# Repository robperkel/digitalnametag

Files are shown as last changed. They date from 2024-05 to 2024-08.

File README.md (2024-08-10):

# E-Paper Digital Nametag

This projects creates a simple re-programmable E-Paper Nametag with the AVR64DU32 microcontroller (MCU). The MCU enumerates as a standard COM serial port when plugged into a computer. 

## Licensing

### Software 
- Code that is automatically generated by MPLAB&reg; Code Configurator (MCC) or pulled from a code example is licensed by Microchip (full agreement is in the header files).
    - The short version is that it is free to use/modify, so long as it uses a Microchip MCU.
- Code that I wrote (firmware and image loading scripts) is licensed under GNU AGPL v3
    - https://choosealicense.com/licenses/agpl-3.0/ 

### Hardware 

- Hardware Design (Schematic and PCB files) are licensed under CERN OHL v2
    - https://choosealicense.com/licenses/cern-ohl-s-2.0/
- 3D models for parts in the PCB are not included due to licensing restrictions. 

## Python Libraries Required (Not Included)

- [Python Image Library (Pillow)](https://pypi.org/project/pillow/)
    - This library opens the image and reads the pixel values.
- [pySerial](https://pypi.org/project/pyserial/)
    - This library allows the script to send data over a COM port.

## Image Configuration  

- Size must be 212 x 104 pixels 
- Colors must only be Red/Black/White
    - The easiest way to achieve this is to use Indexed Color Mode in your image editor
        - Red = 0xFF0000 [255, 0, 0]
        - Black = 0x000000 [0, 0, 0]
        - White = 0xFFFFFF [255, 255, 255]

A test image is provided in the Images folder.

## Programming Connector

This board is designed to use a 6 position Tag-Connect header (such as a [TC2030-ICESPI](https://www.tag-connect.com/product/tc2030-icespi-legged-cable-for-use-with-atmel-ice)) for programming. 

It should be possible to carefully solder wires to the same programming pads to program without this connector, although this may prevent the use of a Tag-Connect header in the future due to the uneven surface created.

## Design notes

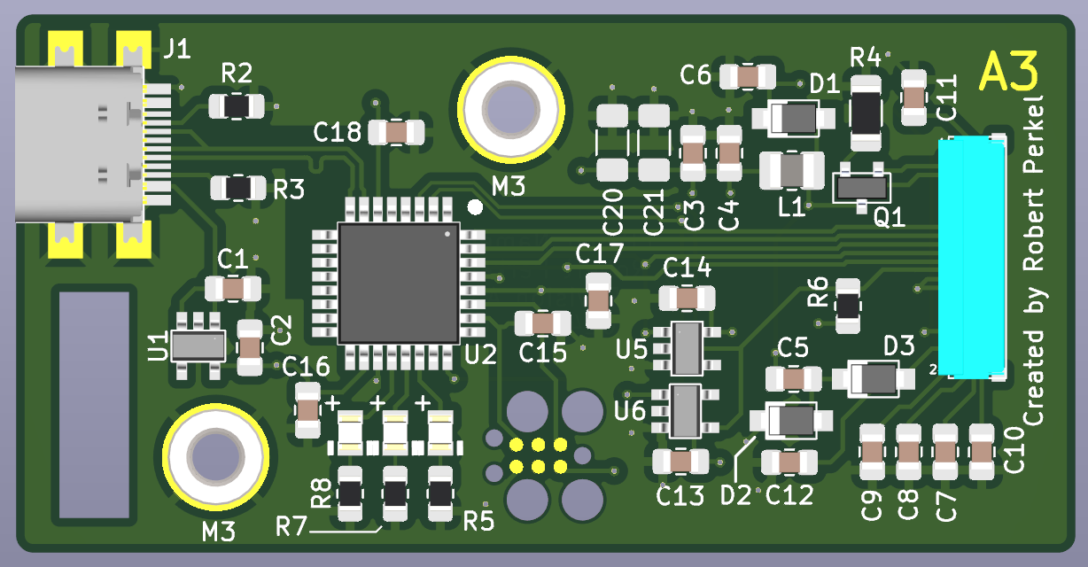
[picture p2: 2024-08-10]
Images/3D Render.png

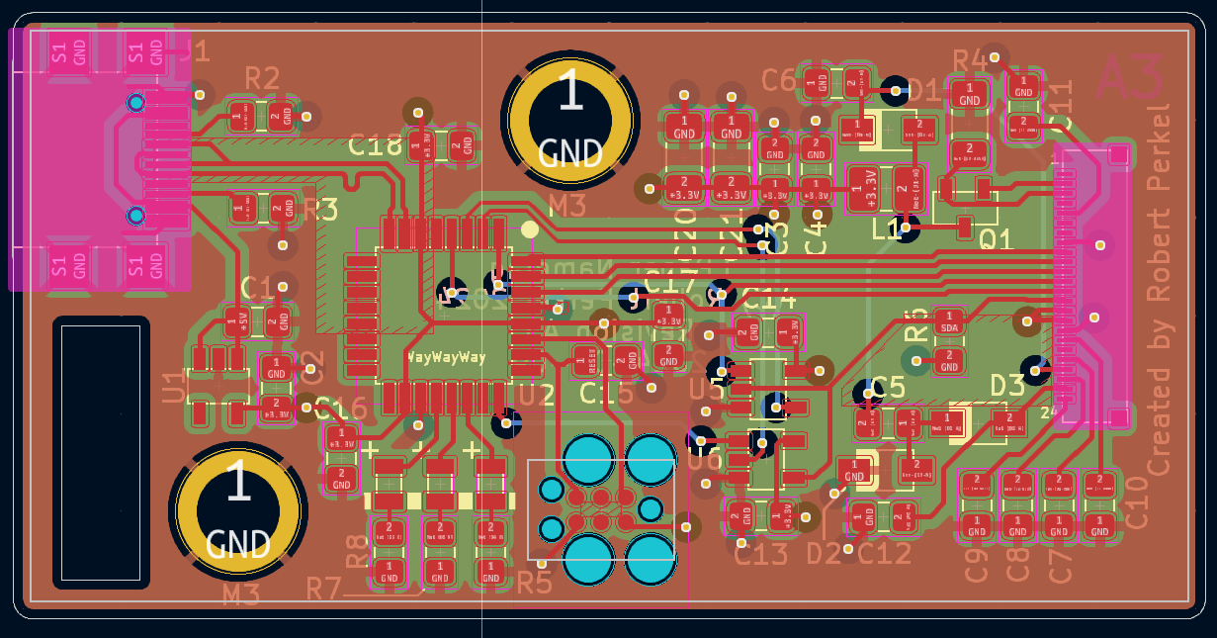
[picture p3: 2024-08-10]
Images/2D Render.png

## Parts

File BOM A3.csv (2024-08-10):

Reference | Value | DNP | Footprint | Qty
C1,C4,C6,C7,C8,C9,C10,C11,C12 | 1uF, 25V |  | Capacitor_SMD:C_0805_2012Metric_Pad1.18x1.45mm_HandSolder | 9
C2 | 2.2uF |  | Capacitor_SMD:C_0805_2012Metric_Pad1.18x1.45mm_HandSolder | 1
C3,C13,C14,C15,C16,C18 | 0.1uF, 16V |  | Capacitor_SMD:C_0805_2012Metric_Pad1.18x1.45mm_HandSolder | 6
C5 | 4.7uF/25V |  | Capacitor_SMD:C_0805_2012Metric_Pad1.18x1.45mm_HandSolder | 1
C17 | 10nF |  | Capacitor_SMD:C_0805_2012Metric_Pad1.18x1.45mm_HandSolder | 1
C20,C21 | 10uF | DNP | Capacitor_SMD:C_1206_3216Metric_Pad1.33x1.80mm_HandSolder | 2
D1,D2,D3 | PMEG3020ER |  | StandardPackages_Custom:SOD-123W | 3
D4,D5,D6 | LED |  | StandardPackages_Custom:LED 0805 | 3
J1 | GSB1C41110SSHR |  | nametag:GSB1C41110SSHR | 1
J2 | ~ |  | nametag:FH34SRJ-24S-0.5SH | 1
L1 | 10uH |  | Inductor_SMD:L_1008_2520Metric_Pad1.43x2.20mm_HandSolder | 1
Q1 | NXV55UN |  | StandardPackages_Custom:SOT23-3 | 1
R2,R3 | 5.1k |  | Resistor_SMD:R_0805_2012Metric_Pad1.20x1.40mm_HandSolder | 2
R4 | 0.47, 0.5W |  | Resistor_SMD:R_1206_3216Metric_Pad1.30x1.75mm_HandSolder | 1
R5,R7,R8 | 470 |  | Resistor_SMD:R_0805_2012Metric_Pad1.20x1.40mm_HandSolder | 3
R6 | 100k |  | Resistor_SMD:R_0805_2012Metric_Pad1.20x1.40mm_HandSolder | 1
U1 | MIC550x |  | StandardPackages_Custom:SOT23-5 | 1
U2 | AVR64DU32 |  | Microchip:7x7 TQFP-32 (PT) | 1
U5,U6 | SN74LV1T125DBV |  | StandardPackages_Custom:SOT23-5 | 2

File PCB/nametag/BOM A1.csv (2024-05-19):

Reference | Value | DNP | Footprint | Qty
C1,C4,C6,C7,C8,C9,C10,C11,C12 | 1uF, 25V |  | Capacitor_SMD:C_0805_2012Metric_Pad1.18x1.45mm_HandSolder | 9
C2 | 2.2uF |  | Capacitor_SMD:C_0805_2012Metric_Pad1.18x1.45mm_HandSolder | 1
C3,C13,C14,C15,C16,C18 | 0.1uF, 16V |  | Capacitor_SMD:C_0805_2012Metric_Pad1.18x1.45mm_HandSolder | 6
C5 | 4.7uF/25V |  | Capacitor_SMD:C_0805_2012Metric_Pad1.18x1.45mm_HandSolder | 1
C17 | 10nF |  | Capacitor_SMD:C_0805_2012Metric_Pad1.18x1.45mm_HandSolder | 1
C19,C23 | 0.1uF, 16V | DNP | Capacitor_SMD:C_0805_2012Metric_Pad1.18x1.45mm_HandSolder | 2
C20,C21 | 10uF | DNP | Capacitor_SMD:C_1206_3216Metric_Pad1.33x1.80mm_HandSolder | 2
CLR0,CLR1,CLR2,R9,SIZE0,SIZE1,SIZE2,SIZE3 | 0 | DNP | Resistor_SMD:R_0603_1608Metric_Pad0.98x0.95mm_HandSolder | 8
D1,D2,D3 | PMEG3020ER |  | StandardPackages_Custom:SOD-123W | 3
D4,D5,D6 | LED |  | StandardPackages_Custom:LED 0805 | 3
J1 | USB_C_Receptacle_USB2.0_14P |  | nametag:12402012E212A | 1
J2 | ~ |  | nametag:FH34SRJ-24S-0.5SH | 1
L1 | 10uH |  | Inductor_SMD:L_1008_2520Metric_Pad1.43x2.20mm_HandSolder | 1
Q1 | NXV55UN |  | StandardPackages_Custom:SOT23-3 | 1
R1 | 0 |  | Resistor_SMD:R_0805_2012Metric_Pad1.20x1.40mm_HandSolder | 1
R2,R3 | 5.1k |  | Resistor_SMD:R_0805_2012Metric_Pad1.20x1.40mm_HandSolder | 2
R4 | 0.47, 0.5W |  | Resistor_SMD:R_1206_3216Metric_Pad1.30x1.75mm_HandSolder | 1
R5,R7,R8 | 470 |  | Resistor_SMD:R_0805_2012Metric_Pad1.20x1.40mm_HandSolder | 3
R6 | 100k |  | Resistor_SMD:R_0805_2012Metric_Pad1.20x1.40mm_HandSolder | 1
U1 | MIC550x |  | StandardPackages_Custom:SOT23-5 | 1
U2 | AVR64DU32 |  | Microchip:7x7 TQFP-32 (PT) | 1
U3 | 23K640 | DNP | Microchip:TSSOP-8 (ST) | 1
U4 | MCP9700x-ETT | DNP | StandardPackages_Custom:SOT23-3 | 1
U5,U6 | SN74LV1T125DBV |  | StandardPackages_Custom:SOT23-5 | 2

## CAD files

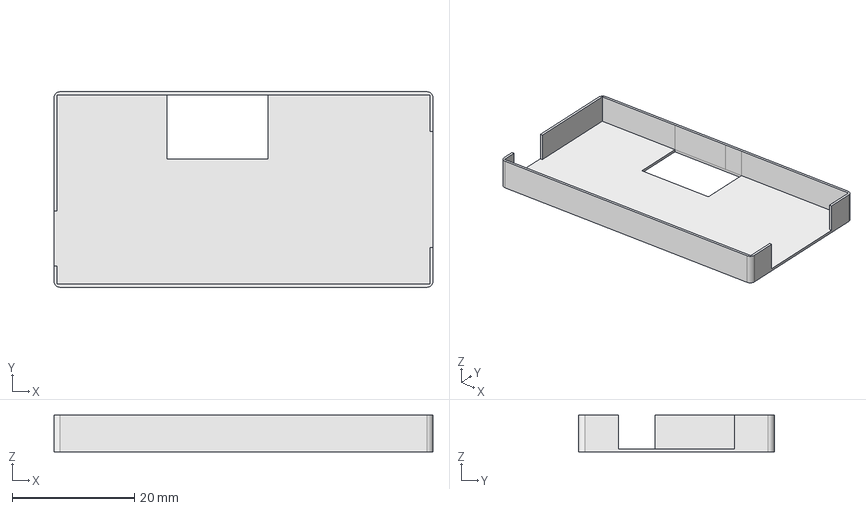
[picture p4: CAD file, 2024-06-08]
3D Models/nametagCase.step
62.0 x 32.0 x 6.00 mm

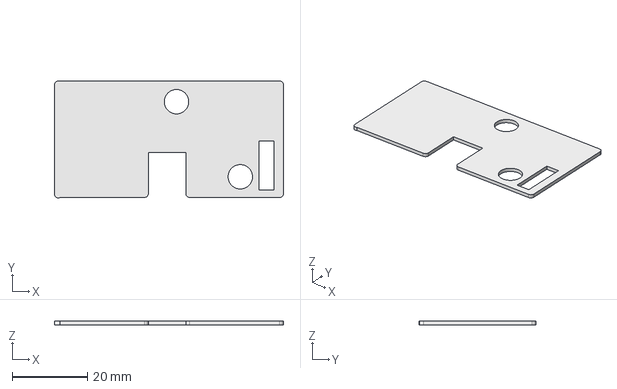
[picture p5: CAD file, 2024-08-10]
Mechanical/displayPlate.step
61.0 x 31.1 x 1.00 mm

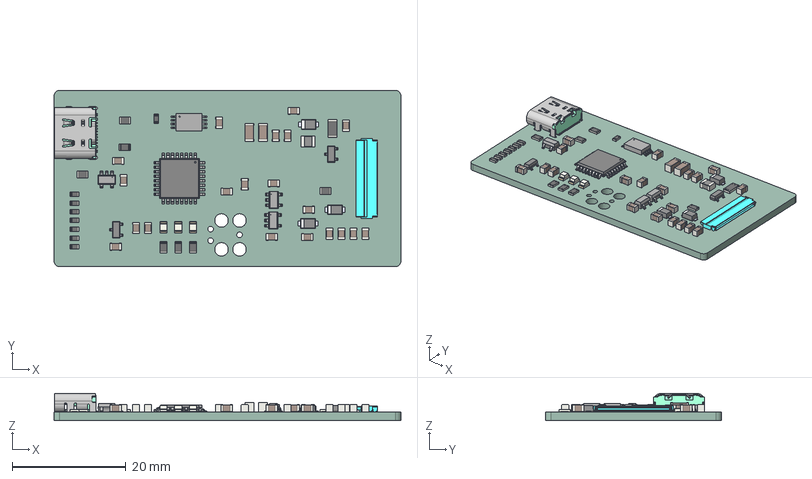
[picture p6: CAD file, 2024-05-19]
PCB/nametag/nametag.step
61.0 x 31.0 x 4.76 mm
C_0805_2012Metric x 20
R_0805_2012Metric x 7
SOT23 x 2
SOD123W x 3
R_0603_1608Metric x 8
LED_0805_2012Metric x 3
R_1206_3216Metric
C_1206_3216Metric x 2
_X2_4E006B21_X0_MOLDING_-261340
FH34SRJ-24S-0.5SH
L_1008_2520Metric
_autosave-nametag_PCB

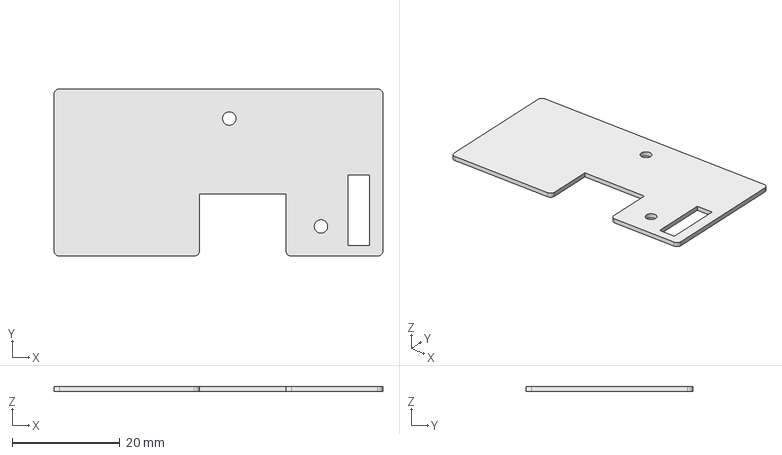
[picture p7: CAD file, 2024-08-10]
Mechanical/backPlate.step
61.0 x 31.0 x 1.00 mm

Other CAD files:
3D Models/nametagCase.FCStd
Mechanical/backPlate.FCStd
Mechanical/displayPlate.FCStd
Old/3D Printed Case/nametagCase.FCStd

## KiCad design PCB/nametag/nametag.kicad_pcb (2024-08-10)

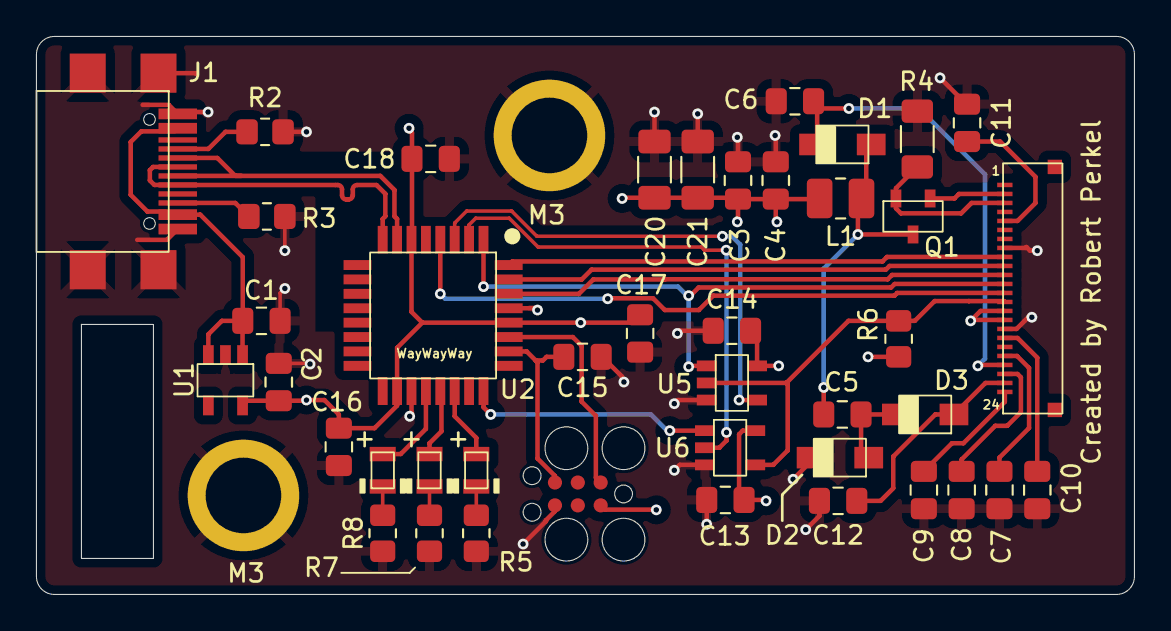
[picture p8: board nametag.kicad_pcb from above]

Board: 4 copper layers, 61.0 x 31.0 mm, 42 parts (0 on the bottom side), 35 nets.

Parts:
C1, C4, C6, C7, C8, C9, C10, C11, C12: 1uF, 25V; C_0805_2012Metric_Pad1.18x1.45mm_HandSolder
C2: 2.2uF; C_0805_2012Metric_Pad1.18x1.45mm_HandSolder
C3, C13, C14, C15, C16, C18: 0.1uF, 16V; C_0805_2012Metric_Pad1.18x1.45mm_HandSolder
C5: 4.7uF/25V; C_0805_2012Metric_Pad1.18x1.45mm_HandSolder
C17: 10nF; C_0805_2012Metric_Pad1.18x1.45mm_HandSolder
C20, C21: 10uF; C_1206_3216Metric_Pad1.33x1.80mm_HandSolder
D1, D2, D3: PMEG3020ER; SOD-123W
D4, D5, D6: LED; LED 0805
J1: GSB1C41110SSHR
J2: FH34SRJ-24S-0.5SH
J3: Conn_02x03_Odd_Even; TC2030-IDC-FP
L1: 10uH; L_1008_2520Metric_Pad1.43x2.20mm_HandSolder
Q1: NXV55UN; SOT23-3
R2, R3: 5.1k; R_0805_2012Metric_Pad1.20x1.40mm_HandSolder
R4: 0.47, 0.5W; R_1206_3216Metric_Pad1.30x1.75mm_HandSolder
R5, R7, R8: 470; R_0805_2012Metric_Pad1.20x1.40mm_HandSolder
R6: 100k; R_0805_2012Metric_Pad1.20x1.40mm_HandSolder
U1: MIC550x; SOT23-5
U2: AVR64DU32; 7x7 TQFP-32 (PT)
U5, U6: SN74LV1T125DBV; SOT23-5

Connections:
+3.3V: C2.2, C3.1, C4.1, C13.1, C14.1, C16.1, C17.1, C18.1, C20.2, C21.2, J2.15 (VDDIO), J2.16 (VDDA), J3.2, L1.1, U1.5 (OUT), U2.6 (VUSB), U2.18 (VDD), U2.28 (VDD), U5.5 (VCC), U6.5 (VCC)
+5V: C1.1, J1.A4 (VBUS), J1.B4 (VBUS), U1.1 (IN), U1.3 (EN)
/D+: J1.A6 (D+), J1.B6 (D+), U2.8 (D+)
/D-: J1.A7 (D-), J1.B7 (D-), U2.7 (D-)
D/C: J2.11 (D/C), U2.30 (PA0)
GND: C1.2, C2.1, C3.2, C4.2, C6.1, C7.1, C8.1, C9.1, C10.1, C11.1, C12.1, C13.2, C14.2, C15.2, C16.2, C17.2, C18.2, C20.1, C21.1, D2.1 (K), J1.A1 (GND), J1.B1 (GND), J1.S1 (SHIELD), J2.8 (BS), J2.17 (GND), J3.6, R2.2, R3.2, R4.1, R5.1, R6.2, R7.1, R8.1, U1.2 (GND), U2.19 (VSS), U2.29 (VSS), U5.3 (GND), U6.3 (GND)
LED_DISP: D4.2 (A), U2.22 (PF2)
LED_MEM: D5.2 (A), U2.21 (PF1)
LED_USB: D6.2 (A), U2.20 (PF0)
MISO: U2.3 (PA5), U5.4 (Y)
MOSI: U2.2 (PA4), U6.2 (A)
unnamed: C5.2, D1.2 (A), L1.2, Q1.3 (D)
unnamed: C6.2, D1.1 (K), J2.21 (VGH)
unnamed: C5.1, D2.2 (A), D3.1 (K)
unnamed: C12.2, D3.2 (A), J2.23 (VGL)
unnamed: D4.1 (K), R5.2
unnamed: D5.1 (K), R7.2
unnamed: D6.1 (K), R8.2
unnamed: J1.A5 (CC1), R2.1
unnamed: J1.B5 (CC2), R3.1
unnamed: J2.2 (GDR), Q1.1 (G)
unnamed: J2.3 (RESE), Q1.2 (S), R4.2
unnamed: C9.2, J2.24 (VCOM)
unnamed: C10.2, J2.18 (VDDD)
unnamed: C7.2, J2.20 (VDH)
unnamed: C11.2, J2.5 (VDHR)
unnamed: C8.2, J2.22 (VDL)
SCLK: J2.13 (SCLK/SCL), U2.4 (PA6)
SDA: J2.14 (SDI/SDA), R6.1, U5.2 (A), U6.4 (Y)
UPDI: J3.1, U2.27 (PF7/UPDI)
~BUSY: J2.9 (~BUSY), U2.32 (PA2)
~DISP_CS: J2.12 (~CS), U2.1 (PA3), U5.1 (~OE)
~DISP_MOSI_EN: U2.24 (PF4), U6.1 (~OE)
~DISP_RESET: J2.10 (~RESET), U2.31 (PA1)
~RESET: C15.1, J3.5, U2.26 (PF6/~RESET)

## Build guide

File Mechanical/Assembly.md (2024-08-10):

# Assembling a Nametag

## Components Needed
Note: Many of these parts are sold in volume, so check the quantity you're buying. 

Parts needed:
- 2x 8mm long, low-profile M3 screws
    - [McMaster-Carr P/N: 93070A064](https://www.mcmaster.com/93070A064/)
- 2x 4mm long, 4.5mm OD Aluminum spacers for M3 screws
    - [McMaster-Carr P/N: 9466A097](https://www.mcmaster.com/94669A097/)
- 2x washers for M3 screws; 0.4-0.6mm thick
    - [McMaster-Carr P/N: 8690A110](https://www.mcmaster.com/98690A110/)
- 1x Steel backing plate (1.5mm thick)
    - Produced by [SendCutSend](https://sendcutsend.com/)
        - G90 Galvanized Steel, 1.5mm thick
        - M3x0.5mm Tapping
- 1x Plastic interposer plate (3mm thick)
    - Produced by [SendCutSend](https://sendcutsend.com/)
        - Acrylic, 3mm thick
- 1x Assembled and tested PCB
- 1x E-Paper Display 
    - [Pervasive Displays: E2213JS0C1](https://www.pervasivedisplays.com/product/2-13-e-ink-displays/#ptab-4)
- A hex key or screwdriver for the screws
- Tape (Scotch tape seems to work well)
- Magnets (recommended: 2x ~5lb magnets)
    - A single 5 lb magnet holds the board up well, but to ensure it is almost impossible for it to fall off accidently, 2x magnets are recommended. 
    - [Apex Magnets P/N: M12x18RUBDI](https://www.apexmagnets.com/magnets/1-2-x-1-8-disc-rubber-coated-neodymium-magnet)

## Assembly

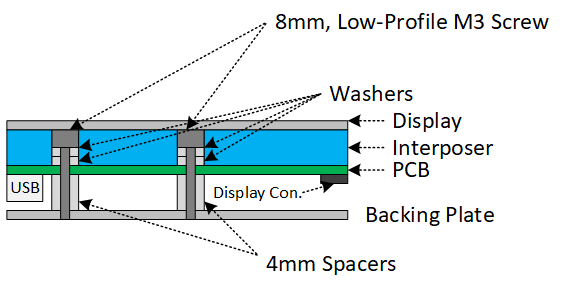
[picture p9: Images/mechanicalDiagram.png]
Cross-Sectional Diagram
  

1. Connect the E-Paper Display to the PCB. The display should be facing up on the component side. 
    - To insert the display: Release the locking lever (lever will be facing up) and slide the cable into the slot. Press on the lever to lock. 
2. Flip the PCB over (component side face down).
3. Take out two M3 screws.
4. Place two washers on each screw.
5. Place the steel backing plate down on the work surface. Verify the screw holes line up with the PCBs holes.
6. Place the spacers on top of the steel mounting plate.
7. Carefully set the PCB on top of the spacers. 
    - Perfect spacer alignment is not required. The assembly self-aligns as both screws fall into place.
8. Take one of the screws (with washers attached) and put it through the holes of the PCB.
9. Gently press down on the PCB, such that the board is level, and turn the screw until it engages with the mounting plate below. When complete, the board shouldn't have a lot of wobble. 
10. Repeat this process for the second screw. Tighten both screws down when finished.
11. Apply tape to the back of the PCB. If using single-sided tape, fold it over to make it double-sided. Avoid applying tape near the programming holes. 
    - Two pieces of tape may be required to ensure the interposer is flush with the board.
12. Place the interposer plate on top of the tape.
13. Apply tape to the top of the interposer plate. Two pieces of tape may be needed to keep the display flush.  
14. Line-up and place the display on the interposer plate, then *gently* press down to ensure it adheres.

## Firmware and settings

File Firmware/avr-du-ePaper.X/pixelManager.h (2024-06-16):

#ifndef PIXELMANAGER_H
#define	PIXELMANAGER_H

#ifdef	__cplusplus
extern "C" {
#endif
    
#include <stdint.h>
#include <stdbool.h>
    
    typedef enum {
        WHITE = 0, BLACK, RED, YELLOW
    } color_t;
    
    typedef enum {
        BW = 0, BWR, BWRY
    } color_mode_t;
    
    //Rotation mode for pixel data
    typedef enum {
        LANDSCAPE_STANDARD, LANDSCAPE_FLIPPED, PORTRAIT_STANDARD, PORTRAIT_FLIPPED
    } screen_orientation_t;
    
#define DEFAULT_PANEL_X 104UL
#define DEFAULT_PANEL_Y 212UL
#define DEFAULT_PANEL_COLOR BWR
#define DEFAULT_ORIENTATION LANDSCAPE_STANDARD
    
//Size of the internal memory buffer
#define PIXEL_MEMORY_BUFFER_SIZE 5512UL
    
    //Init internal variables
    void PixelManager_Initialize(void);
    
    //Set display properties
    void PixelManager_SetDisplayWidth(uint16_t width);
    void PixelManager_SetDisplayHeight(uint16_t height);
    void PixelManager_SetDisplayColors(color_mode_t mode);
    void PixelManager_SetRotationMode(screen_orientation_t position);
    
    //Get display properties
    uint16_t PixelManager_GetDisplayWidth(void);
    uint16_t PixelManager_GetDisplayHeight(void);
    color_mode_t PixelManager_GetDisplayColors(void);
    screen_orientation_t PixelManager_GetRotationMode(void);
    
    //Get data byte for image loading
    uint8_t PixelManager_GetBWByte(uint16_t x, uint16_t y);
    uint8_t PixelManager_GetRByte(uint16_t x, uint16_t y);
    uint8_t PixelManager_GetBWRYByte(uint16_t x, uint16_t y);
    
    //Starts a new image stream
    void PixelManager_ResetSeqPixelPointers(void);
    
    //Loads data into buffer
    void PixelManager_LoadPixelStream(color_t clr);
    
    //Sets a pixel to the specified color
    void PixelManager_SetPixel(uint16_t x, uint16_t y, color_t color);
    
#ifdef	__cplusplus
}
#endif

#endif	/* PIXELMANAGER_H */

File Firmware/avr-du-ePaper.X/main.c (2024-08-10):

 /*
 * MAIN Generated Driver File
 * 
 * @file main.c
 * 
 * @defgroup main MAIN
 * 
 * @brief This is the generated driver implementation file for the MAIN driver.
 *
 * @version MAIN Driver Version 1.0.0
*/

/*
© [2024] Microchip Technology Inc. and its subsidiaries.

    Subject to your compliance with these terms, you may use Microchip 
    software and any derivatives exclusively with Microchip products. 
    You are responsible for complying with 3rd party license terms  
    applicable to your use of 3rd party software (including open source  
    software) that may accompany Microchip software. SOFTWARE IS ?AS IS.? 
    NO WARRANTIES, WHETHER EXPRESS, IMPLIED OR STATUTORY, APPLY TO THIS 
    SOFTWARE, INCLUDING ANY IMPLIED WARRANTIES OF NON-INFRINGEMENT,  
    MERCHANTABILITY, OR FITNESS FOR A PARTICULAR PURPOSE. IN NO EVENT 
    WILL MICROCHIP BE LIABLE FOR ANY INDIRECT, SPECIAL, PUNITIVE, 
    INCIDENTAL OR CONSEQUENTIAL LOSS, DAMAGE, COST OR EXPENSE OF ANY 
    KIND WHATSOEVER RELATED TO THE SOFTWARE, HOWEVER CAUSED, EVEN IF 
    MICROCHIP HAS BEEN ADVISED OF THE POSSIBILITY OR THE DAMAGES ARE 
    FORESEEABLE. TO THE FULLEST EXTENT ALLOWED BY LAW, MICROCHIP?S 
    TOTAL LIABILITY ON ALL CLAIMS RELATED TO THE SOFTWARE WILL NOT 
    EXCEED AMOUNT OF FEES, IF ANY, YOU PAID DIRECTLY TO MICROCHIP FOR 
    THIS SOFTWARE.
*/
#include "mcc_generated_files/system/system.h"
#include "ePaper_3CLR.h"
#include "mcc_generated_files/timer/delay.h"
#include "usb_cdc_virtual_serial_port.h"
#include "ringBuffer.h"
#include "pixelManager.h"
#include "Application.h"
#include "textQueue.h"

#include <stdint.h>
#include <stdbool.h>

#define TX_BUFFER_SIZE 32

int main(void)
{
    SYSTEM_Initialize();
    SPI0_Host_Open(HOST_CONFIG);

    TextQueue_Initialize();
    Application_Initialize();
    PixelManager_Initialize();
    
    USB_Stop();
    
    //Enumerate USB
    if (USB_Start() == SUCCESS)
    {
        LED_USB_SetHigh();
    }
        
    //Enable Interrupts
    sei();
        
    uint8_t data = 0x00;
        
    while(1)
    {
        USB_CDCVirtualSerialPortHandler();
        USBDevice_Handle();
        
        //Handle any input data
        while (USB_CDCRead(&data) == CDC_SUCCESS)
        {
            Application_AcceptData(data);
        }
        
        //Process data
        Application_HandleUSBInput();
        
        //Send Queued Text
        TextQueue_LoadUSB();
        
    }    
}

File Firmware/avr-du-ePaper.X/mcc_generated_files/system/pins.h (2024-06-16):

/**
 * Generated Pins header File
 * 
 * @file pins.h
 * 
 * @defgroup  pinsdriver Pins Driver
 * 
 * @brief This is generated driver header for pins. 
 *        This header file provides APIs for all pins selected in the GUI.
 *
 * @version Driver Version  1.1.0
*/

/*
© [2024] Microchip Technology Inc. and its subsidiaries.

    Subject to your compliance with these terms, you may use Microchip 
    software and any derivatives exclusively with Microchip products. 
    You are responsible for complying with 3rd party license terms  
    applicable to your use of 3rd party software (including open source  
    software) that may accompany Microchip software. SOFTWARE IS ?AS IS.? 
    NO WARRANTIES, WHETHER EXPRESS, IMPLIED OR STATUTORY, APPLY TO THIS 
    SOFTWARE, INCLUDING ANY IMPLIED WARRANTIES OF NON-INFRINGEMENT,  
    MERCHANTABILITY, OR FITNESS FOR A PARTICULAR PURPOSE. IN NO EVENT 
    WILL MICROCHIP BE LIABLE FOR ANY INDIRECT, SPECIAL, PUNITIVE, 
    INCIDENTAL OR CONSEQUENTIAL LOSS, DAMAGE, COST OR EXPENSE OF ANY 
    KIND WHATSOEVER RELATED TO THE SOFTWARE, HOWEVER CAUSED, EVEN IF 
    MICROCHIP HAS BEEN ADVISED OF THE POSSIBILITY OR THE DAMAGES ARE 
    FORESEEABLE. TO THE FULLEST EXTENT ALLOWED BY LAW, MICROCHIP?S 
    TOTAL LIABILITY ON ALL CLAIMS RELATED TO THE SOFTWARE WILL NOT 
    EXCEED AMOUNT OF FEES, IF ANY, YOU PAID DIRECTLY TO MICROCHIP FOR 
    THIS SOFTWARE.
*/

#ifndef PINS_H_INCLUDED
#define PINS_H_INCLUDED

#include <avr/io.h>
#include "./port.h"

//get/set MISO aliases
#define MISO_SetHigh() do { PORTA_OUTSET = 0x20; } while(0)
#define MISO_SetLow() do { PORTA_OUTCLR = 0x20; } while(0)
#define MISO_Toggle() do { PORTA_OUTTGL = 0x20; } while(0)
#define MISO_GetValue() (VPORTA.IN & (0x1 << 5))
#define MISO_SetDigitalInput() do { PORTA_DIRCLR = 0x20; } while(0)
#define MISO_SetDigitalOutput() do { PORTA_DIRSET = 0x20; } while(0)
#define MISO_SetPullUp() do { PORTA_PIN5CTRL  |= PORT_PULLUPEN_bm; } while(0)
#define MISO_ResetPullUp() do { PORTA_PIN5CTRL  &= ~PORT_PULLUPEN_bm; } while(0)
#define MISO_SetInverted() do { PORTA_PIN5CTRL  |= PORT_INVEN_bm; } while(0)
#define MISO_ResetInverted() do { PORTA_PIN5CTRL  &= ~PORT_INVEN_bm; } while(0)
#define MISO_DisableInterruptOnChange() do { PORTA.PIN5CTRL = (PORTA.PIN5CTRL & ~PORT_ISC_gm) | 0x0 ; } while(0)
#define MISO_EnableInterruptForBothEdges() do { PORTA.PIN5CTRL = (PORTA.PIN5CTRL & ~PORT_ISC_gm) | 0x1 ; } while(0)
#define MISO_EnableInterruptForRisingEdge() do { PORTA.PIN5CTRL = (PORTA.PIN5CTRL & ~PORT_ISC_gm) | 0x2 ; } while(0)
#define MISO_EnableInterruptForFallingEdge() do { PORTA.PIN5CTRL = (PORTA.PIN5CTRL & ~PORT_ISC_gm) | 0x3 ; } while(0)
#define MISO_DisableDigitalInputBuffer() do { PORTA.PIN5CTRL = (PORTA.PIN5CTRL & ~PORT_ISC_gm) | 0x4 ; } while(0)
#define MISO_EnableInterruptForLowLevelSensing() do { PORTA.PIN5CTRL = (PORTA.PIN5CTRL & ~PORT_ISC_gm) | 0x5 ; } while(0)
#define PA5_SetInterruptHandler MISO_SetInterruptHandler

//get/set MOSI aliases
#define MOSI_SetHigh() do { PORTA_OUTSET = 0x10; } while(0)
#define MOSI_SetLow() do { PORTA_OUTCLR = 0x10; } while(0)
#define MOSI_Toggle() do { PORTA_OUTTGL = 0x10; } while(0)
#define MOSI_GetValue() (VPORTA.IN & (0x1 << 4))
#define MOSI_SetDigitalInput() do { PORTA_DIRCLR = 0x10; } while(0)
#define MOSI_SetDigitalOutput() do { PORTA_DIRSET = 0x10; } while(0)
#define MOSI_SetPullUp() do { PORTA_PIN4CTRL  |= PORT_PULLUPEN_bm; } while(0)
#define MOSI_ResetPullUp() do { PORTA_PIN4CTRL  &= ~PORT_PULLUPEN_bm; } while(0)
#define MOSI_SetInverted() do { PORTA_PIN4CTRL  |= PORT_INVEN_bm; } while(0)
#define MOSI_ResetInverted() do { PORTA_PIN4CTRL  &= ~PORT_INVEN_bm; } while(0)
#define MOSI_DisableInterruptOnChange() do { PORTA.PIN4CTRL = (PORTA.PIN4CTRL & ~PORT_ISC_gm) | 0x0 ; } while(0)
#define MOSI_EnableInterruptForBothEdges() do { PORTA.PIN4CTRL = (PORTA.PIN4CTRL & ~PORT_ISC_gm) | 0x1 ; } while(0)
#define MOSI_EnableInterruptForRisingEdge() do { PORTA.PIN4CTRL = (PORTA.PIN4CTRL & ~PORT_ISC_gm) | 0x2 ; } while(0)
#define MOSI_EnableInterruptForFallingEdge() do { PORTA.PIN4CTRL = (PORTA.PIN4CTRL & ~PORT_ISC_gm) | 0x3 ; } while(0)
#define MOSI_DisableDigitalInputBuffer() do { PORTA.PIN4CTRL = (PORTA.PIN4CTRL & ~PORT_ISC_gm) | 0x4 ; } while(0)
#define MOSI_EnableInterruptForLowLevelSensing() do { PORTA.PIN4CTRL = (PORTA.PIN4CTRL & ~PORT_ISC_gm) | 0x5 ; } while(0)
#define PA4_SetInterruptHandler MOSI_SetInterruptHandler

//get/set SCLK aliases
#define SCLK_SetHigh() do { PORTA_OUTSET = 0x40; } while(0)
#define SCLK_SetLow() do { PORTA_OUTCLR = 0x40; } while(0)
#define SCLK_Toggle() do { PORTA_OUTTGL = 0x40; } while(0)
#define SCLK_GetValue() (VPORTA.IN & (0x1 << 6))
#define SCLK_SetDigitalInput() do { PORTA_DIRCLR = 0x40; } while(0)
#define SCLK_SetDigitalOutput() do { PORTA_DIRSET = 0x40; } while(0)
#define SCLK_SetPullUp() do { PORTA_PIN6CTRL  |= PORT_PULLUPEN_bm; } while(0)
#define SCLK_ResetPullUp() do { PORTA_PIN6CTRL  &= ~PORT_PULLUPEN_bm; } while(0)
#define SCLK_SetInverted() do { PORTA_PIN6CTRL  |= PORT_INVEN_bm; } while(0)
#define SCLK_ResetInverted() do { PORTA_PIN6CTRL  &= ~PORT_INVEN_bm; } while(0)
#define SCLK_DisableInterruptOnChange() do { PORTA.PIN6CTRL = (PORTA.PIN6CTRL & ~PORT_ISC_gm) | 0x0 ; } while(0)
#define SCLK_EnableInterruptForBothEdges() do { PORTA.PIN6CTRL = (PORTA.PIN6CTRL & ~PORT_ISC_gm) | 0x1 ; } while(0)
#define SCLK_EnableInterruptForRisingEdge() do { PORTA.PIN6CTRL = (PORTA.PIN6CTRL & ~PORT_ISC_gm) | 0x2 ; } while(0)
#define SCLK_EnableInterruptForFallingEdge() do { PORTA.PIN6CTRL = (PORTA.PIN6CTRL & ~PORT_ISC_gm) | 0x3 ; } while(0)
#define SCLK_DisableDigitalInputBuffer() do { PORTA.PIN6CTRL = (PORTA.PIN6CTRL & ~PORT_ISC_gm) | 0x4 ; } while(0)
#define SCLK_EnableInterruptForLowLevelSensing() do { PORTA.PIN6CTRL = (PORTA.PIN6CTRL & ~PORT_ISC_gm) | 0x5 ; } while(0)
#define PA6_SetInterruptHandler SCLK_SetInterruptHandler
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

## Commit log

2024-05-05 Added new firmware
    [nametag.kicad_pcb, nametag.kicad_sch]
2024-05-16 Schematic complete
    [nametag.kicad_pcb, nametag.kicad_sch]
2024-05-17 PCB WIP
    [nametag.kicad_pcb, nametag.kicad_sch]
2024-05-19 PCB files. BOM. Step model.
    [BOM A1.csv, nametag.kicad_pcb, nametag.kicad_sch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]
2024-06-01 Implemented Pixel Manager
    [nametag.kicad_pcb]
2024-06-08 Firmware enhancements. C# Code changes
    [nametagCase.FCStd, nametagCase.step]
2024-06-16 Created common SPI library
    [backPlate.FCStd, backPlate.step, displayPlate.FCStd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]
2024-08-10 Cleaned-up repository
    [backPlate.FCStd, backPlate.step, displayPlate.FCStd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]
2024-08-10 README edits. Added renders and BOM
    [BOM A3.csv, nametag.kicad_pcb, nametag.kicad_sch]
